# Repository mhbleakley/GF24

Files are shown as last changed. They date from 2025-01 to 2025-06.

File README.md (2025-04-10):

# GeoFence 2024



A dog collar with GNSS capabilities and an alarm, allowing the user to set a virtual fenced area. When the collar leaves the fenced area, the alarm sounds.

View schematic/board [here](https://kicanvas.org/?github=https%3A%2F%2Fgithub.com%2Fmhbleakley%2FGF24) (you will have to select board or schematic from right panel).

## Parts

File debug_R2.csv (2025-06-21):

Reference | Footprint | Manufacturer PN | Distributor Link
BT1 | MB-SW:Solder_Joint_1_2
BZ1 | MB-Buzzer:SMTB-0927-TW-R | 668-SMTB-0927-TW-RTR-ND | https://www.digikey.com/en/products/detail/pui-audio-inc/smtb-0927-tw-r/13165907
C1,C2,C6,C14,C17,C18 | Capacitor_SMD:C_0603_1608Metric | 399-13217-2-ND | https://www.digikey.com/en/products/detail/kemet/C1210C105K8RACTU/2216484
C3 | Capacitor_SMD:C_0603_1608Metric | 399-C0603C103K8RACTUTR-ND | https://www.digikey.com/en/products/detail/kemet/C0603C103K8RACTU/2199758
C4 | Capacitor_SMD:C_0805_2012Metric | 399-C1210C475K8RACTUTR-ND | https://www.digikey.com/en/products/detail/kemet/C1210C475K8RACTU/2216925
C5,C8,C10,C12,C13,C15,C16,C19 | Capacitor_SMD:C_0805_2012Metric | 399-C0805C104K8RACTUTR-ND | https://www.digikey.com/en/products/detail/kemet/C0805C104K8RACTU/2211745
C7,C9,C11 | Capacitor_SMD:C_0805_2012Metric | 399-C1210C106K8RACTUTR-ND | https://www.digikey.com/en/products/detail/kemet/C1210C106K8RACTU/2216503
D1,D2,D3,D4 | MB-Opto:WE-0603-Mono-Chip-Advance | 732-150060RS75003TR-ND | https://www.digikey.com/en/products/detail/w%C3%BCrth-elektronik/150060RS75003/16022171
D5,D6,D7,D8 | MB-Opto:WE-1204-Mono-Side | 732-5024-2-ND | https://www.digikey.com/en/products/detail/w%C3%BCrth-elektronik/155124GS73200/4490038
D9 | MB-SOD:SOD-123-2 | MMSD4148T1GOSTR-ND | https://www.digikey.com/en/products/detail/onsemi/mmsd4148t1g/919705
J1 | MB-Conn:GCT_USB4110GFA | 2073-USB4110-GF-A-2-ND | https://www.digikey.com/en/products/detail/gct/usb4110-gf-a/10384547
J4 | Connector_PinHeader_2.54mm:PinHeader_1x04_P2.54mm_Horizontal | S9016E-04-ND | https://www.digikey.com/en/products/detail/sullins-connector-solutions/GRPB041VWCN-RC/1786467
Q1 | Package_TO_SOT_SMD:SOT-323_SC-70 | MMBT3904LT1GOSTR-ND | https://www.digikey.com/en/products/detail/onsemi/mmbt3904lt1g/919601
R1 | MB-Generic:R0603_medium | 311-4.12KHRTR-ND | https://www.digikey.com/en/products/detail/yageo/rc0603fr-074k12l/727204
R2,R3 | MB-Generic:R0603_medium | 311-261HRTR-ND | https://www.digikey.com/en/products/detail/yageo/RC0603FR-07261RL/727095
R4,R5,R6,R8,R9 | MB-Generic:R0603_medium | 311-1.00KHRTR-ND | https://www.digikey.com/en/products/detail/yageo/rc0603fr-071kl/726843
R7 | MB-Generic:R0603_medium | 311-1.50KHRTR-ND | https://www.digikey.com/en/products/detail/yageo/rc0603fr-071k5l/726864
R10,R11,R12 | MB-Generic:R0603_medium | 311-10.0KHRTR-ND | https://www.digikey.com/en/products/detail/yageo/rc0603fr-0710kl/726880
R13 | MB-Generic:R0603_medium | 311-180HRTR-ND | https://www.digikey.com/en/products/detail/yageo/rc0603fr-07180rl/726994
R14,R15,R16 | MB-Generic:R0603_medium | 13-RC0603JR-072RLTR-ND | https://www.digikey.com/en/products/detail/yageo/RC0603JR-072RL/5918445
SW1,SW4 | MB-SW:Solder_Joint_1_2
SW2 | MB-SW:PTS815SJM250SMTRLFS | CKN12215-2-ND | https://www.digikey.com/en/products/detail/c-k/pts815sjm250smtrlfs/9947846
SW3 | Button_Switch_SMD:Nidec_Copal_CAS-120A | 563-1021-2-ND | https://www.digikey.com/en/products/detail/nidec-components-corporation/cjs-1200ta/948332
SW5 | MB-SW:Solder_Joint_1_2
TH1 | MB-Generic:R0603_medium | 490-18139-2-ND | https://www.digikey.com/en/products/detail/murata-electronics/ncu18xh103f6srb/7243451
TP1,TP2,TP3,TP4,TP5,TP6 | TestPoint:TestPoint_Pad_D1.5mm
U1 | Package_TO_SOT_SMD:SOT-223-6 | 296-13810-2-ND | https://www.digikey.com/en/products/detail/texas-instruments/tps79533dcqr/510347
U2 | MB-MSOP:10-MSOP-TE | LTC1733EMSE#TRPBFTR-ND | https://www.digikey.com/en/products/detail/analog-devices-inc/ltc1733emse-trpbf/961156
U3 | MB-GNSS:SAM-M10Q | 672-SAM-M10Q-00BTR-ND | https://www.digikey.com/en/products/detail/u-blox/sam-m10q-00b/16672678
U4 | Package_QFP:LQFP-48_7x7mm_P0.5mm | 497-8307-ND | https://www.digikey.com/en/products/detail/stmicroelectronics/STM32F102C8T6/1956086
X1 | Oscillator:Oscillator_SMD_ECS_2520MV-xxx-xx-4Pin_2.5x2.0mm | XC3030TR-ND | https://www.digikey.com/en/products/detail/ecs-inc/ecs-2520mv-160-cn-tr/9742387

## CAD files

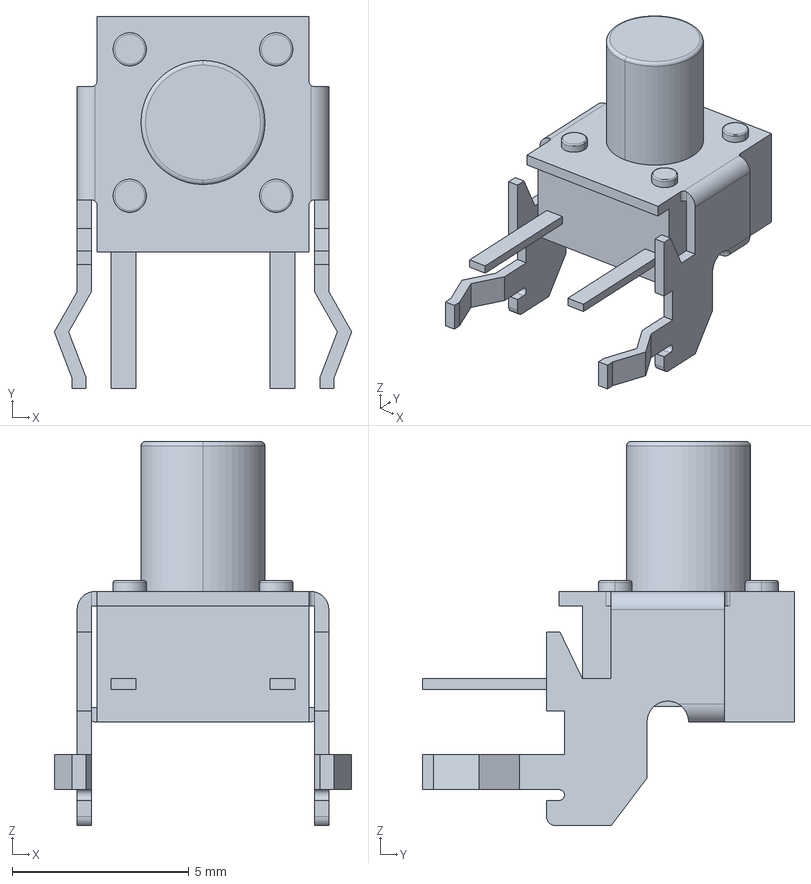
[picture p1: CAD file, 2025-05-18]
3D/1_1825027_7/c-1-1825027-7-g-3d.stp
8.41 x 10.5 x 10.9 mm

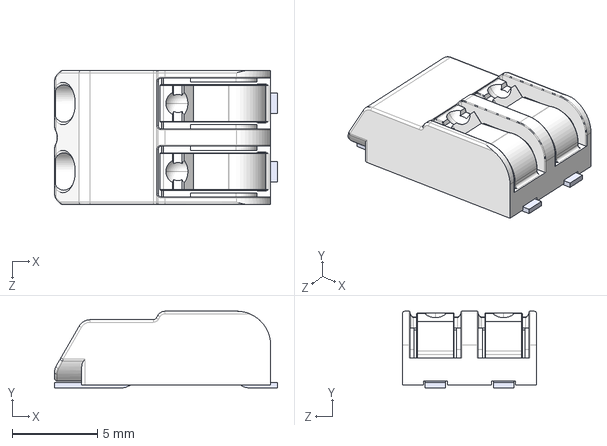
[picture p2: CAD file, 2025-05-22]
3D/2060_452_998_404/2060-452_998-404.step
13.1 x 4.50 x 7.90 mm

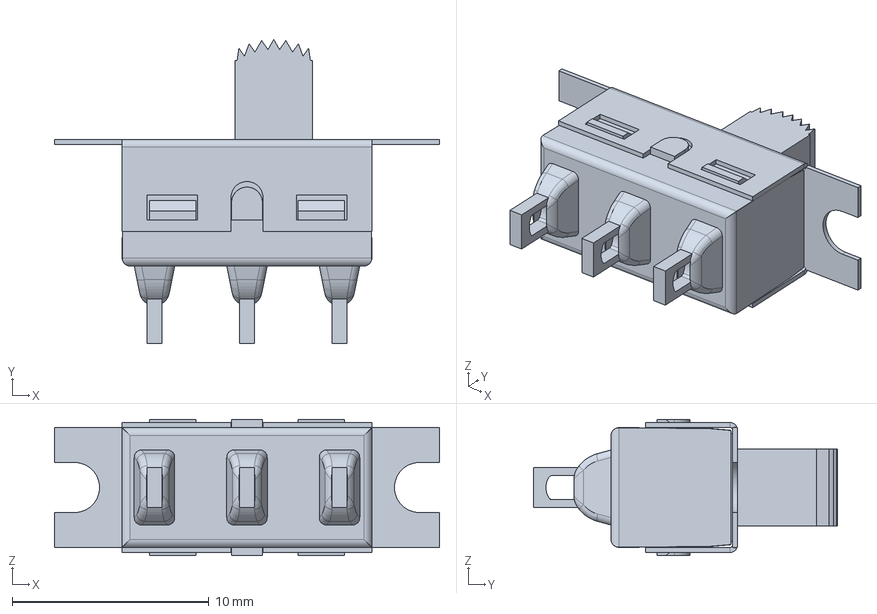
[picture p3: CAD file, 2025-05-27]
3D/CKCOMPONENTS_1101M1S3ZBE2/1101M1S3ZBE2.stp
19.6 x 15.4 x 6.91 mm

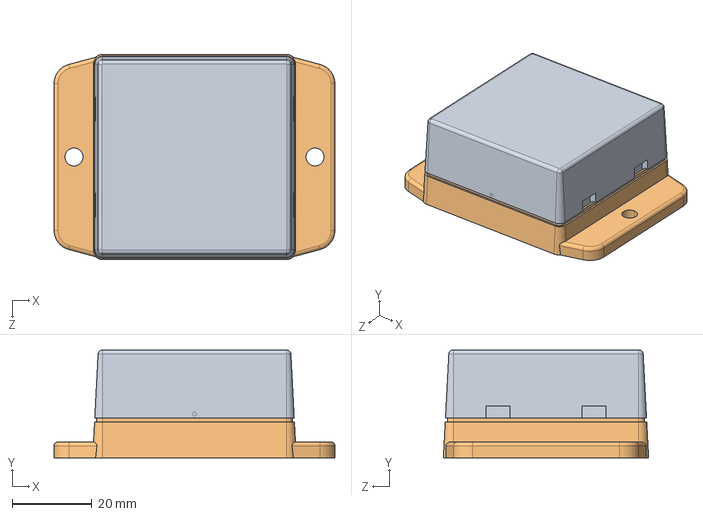
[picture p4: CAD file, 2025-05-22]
3D/CU-18422.Step
70.4 x 27.0 x 51.4 mm
18422-C
18422-B

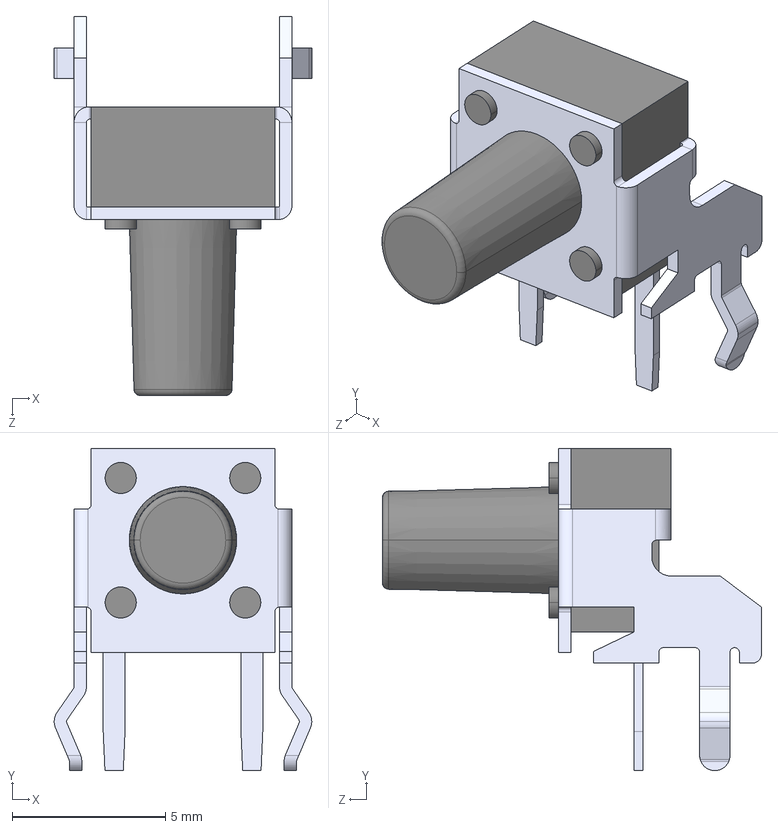
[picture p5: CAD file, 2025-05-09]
3D/1-1825027-1.step
8.41 x 10.5 x 12.4 mm

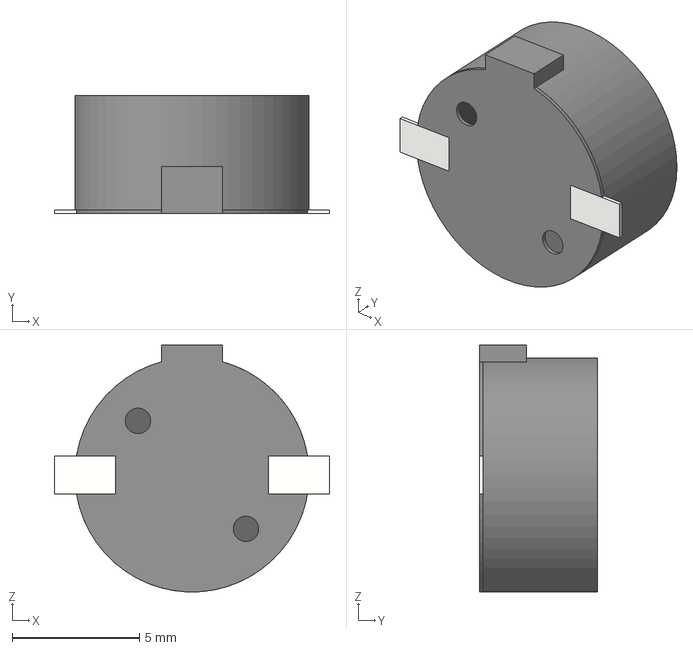
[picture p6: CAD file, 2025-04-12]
3D/SMTB-0927-TW-R--3DModel-STEP-461651.STEP
10.8 x 4.65 x 9.70 mm

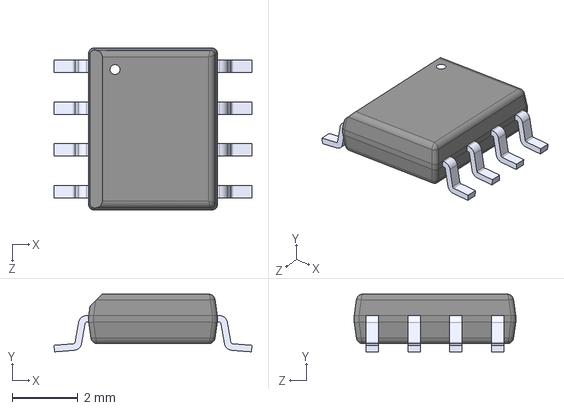
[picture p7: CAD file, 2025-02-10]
3D/M24C02-WMN6TP.step
6.00 x 1.75 x 4.90 mm

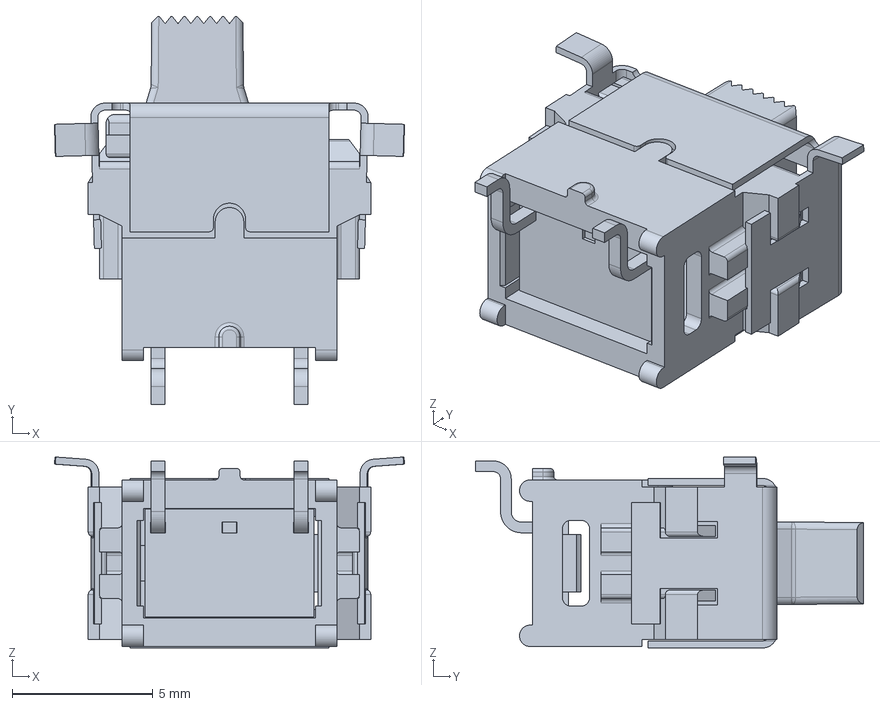
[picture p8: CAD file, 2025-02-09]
3D/ES02MSABE.stp
12.4 x 13.8 x 6.78 mm
ES02MSABE_PART1
ES02MSABE_PART2
ES02MSABE_PART3

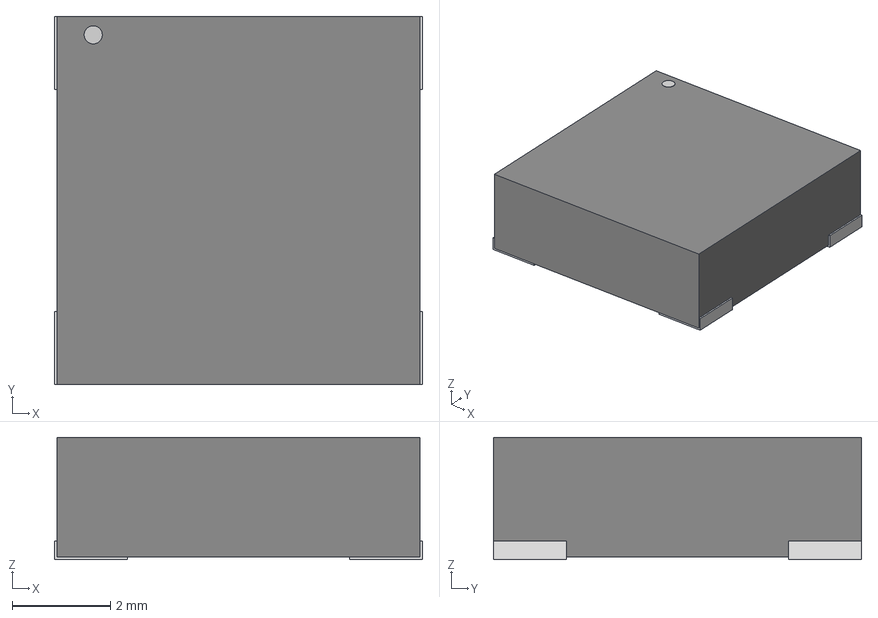
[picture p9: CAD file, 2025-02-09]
3D/ST-025BH_SOB.step
7.49 x 7.49 x 2.49 mm

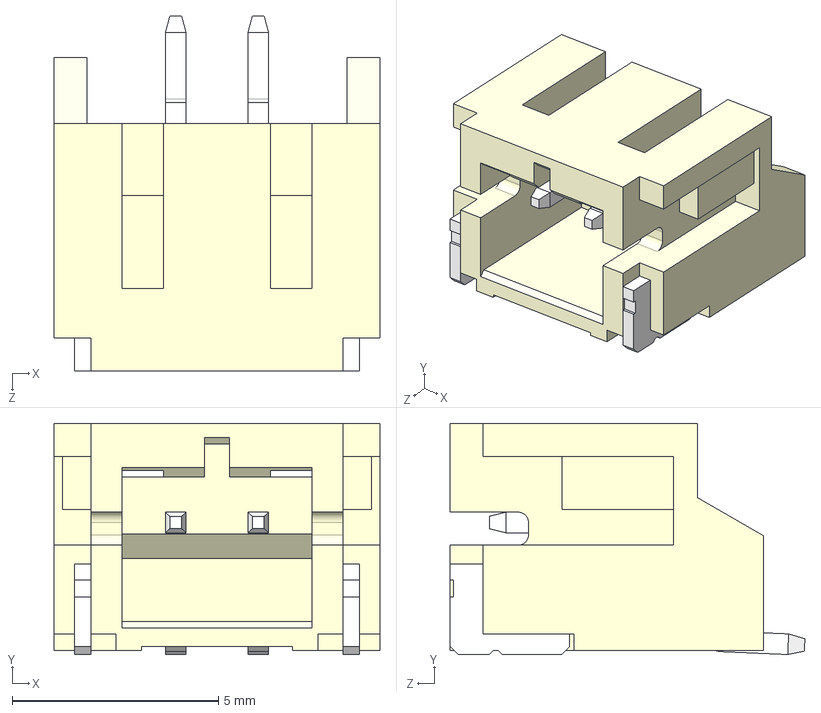
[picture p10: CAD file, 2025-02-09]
3D/S2B-PH-SM4-TB--3DModel-STEP-269445.STEP
7.90 x 5.60 x 8.60 mm

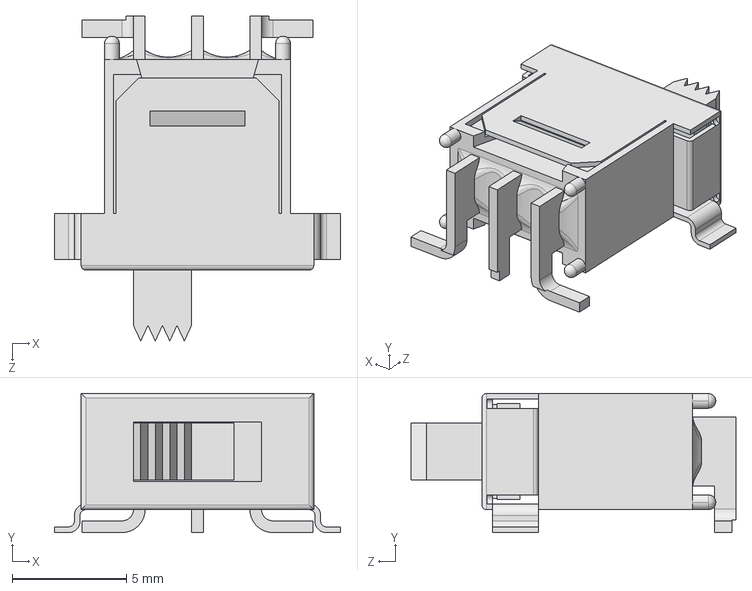
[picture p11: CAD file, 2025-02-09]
3D/500ASSP1SM6QE.step
12.5 x 6.08 x 14.2 mm

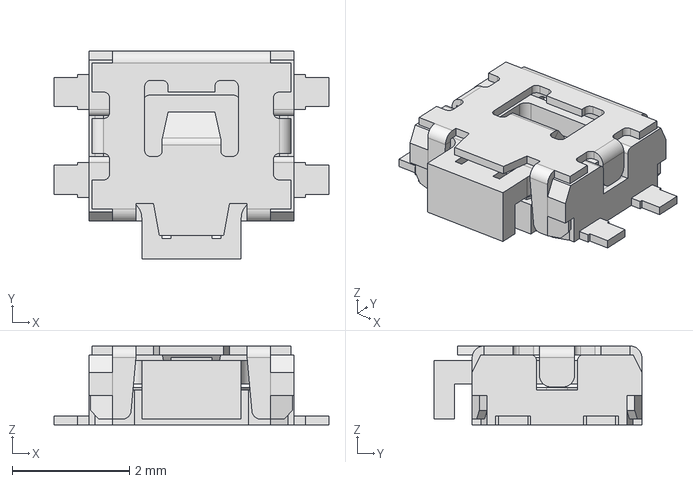
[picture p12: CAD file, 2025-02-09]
3D/TL1016AAFxxxQG.stp
4.70 x 3.55 x 1.35 mm

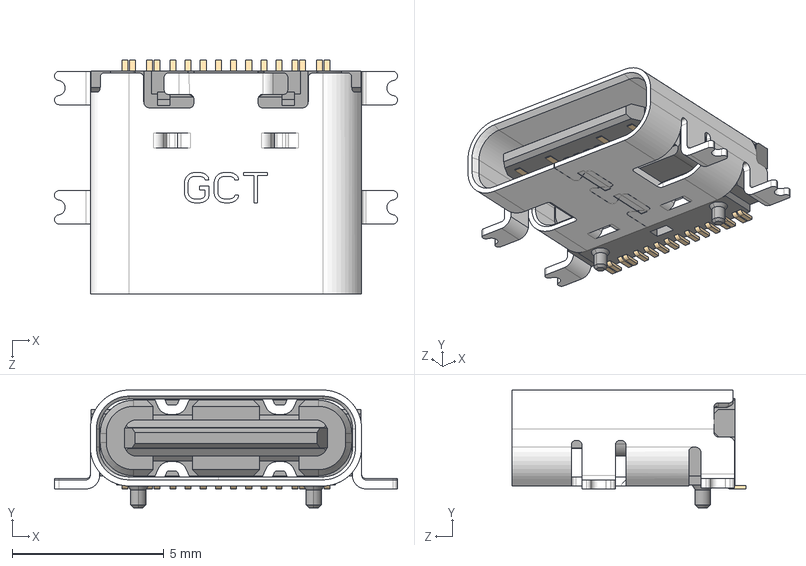
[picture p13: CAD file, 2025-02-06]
3D/USB4110GFA.step
11.3 x 3.89 x 7.70 mm

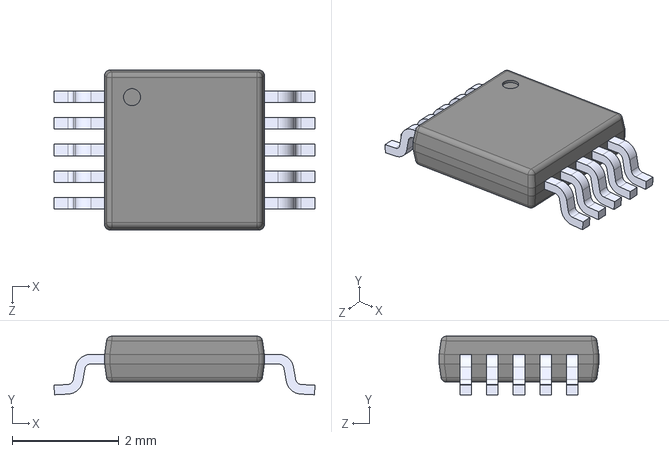
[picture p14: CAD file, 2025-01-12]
3D/LTC1733EMSE_TRPBF.step
4.90 x 1.10 x 3.00 mm

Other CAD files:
3D/NX2016SA_NDK.step
3D/1101M2S5AQE2.stp
3D/3220-10-0100-00--3DModel-STEP-56544.STEP
3D/PTS815SJM250SMTRLFS.stp
3D/0533980671--3DModel-STEP-361473.STEP
3D/0533980671/0533980671.step
3D/2137160001.step
3D/54.STEP
3D/APBDA3020.STEP
3D/APDA3020.STEP
3D/C0402C103K9RACTU.STEP
3D/C0603C103K9RACTU.STEP
3D/C0805C104K9RACTU.step
3D/C1206C475K9RACTU.step
3D/CJS-1200TA.step
3D/CSQG703BP.step
3D/ETQ-P3M2R2HFP.STEP
3D/LM3671MF-3.3.step
3D/M24256-BFMC6TG.step
3D/MAX-M10S-00B--3DModel-STEP-269445.STEP
3D/MMSD4148T1G.STEP
3D/RC0603FR-0710KL.STEP
3D/RC1206JR-1010KL.step
3D/SAM-M8Q-0.STEP
3D/TPS74533PQWDRVRQ1.step

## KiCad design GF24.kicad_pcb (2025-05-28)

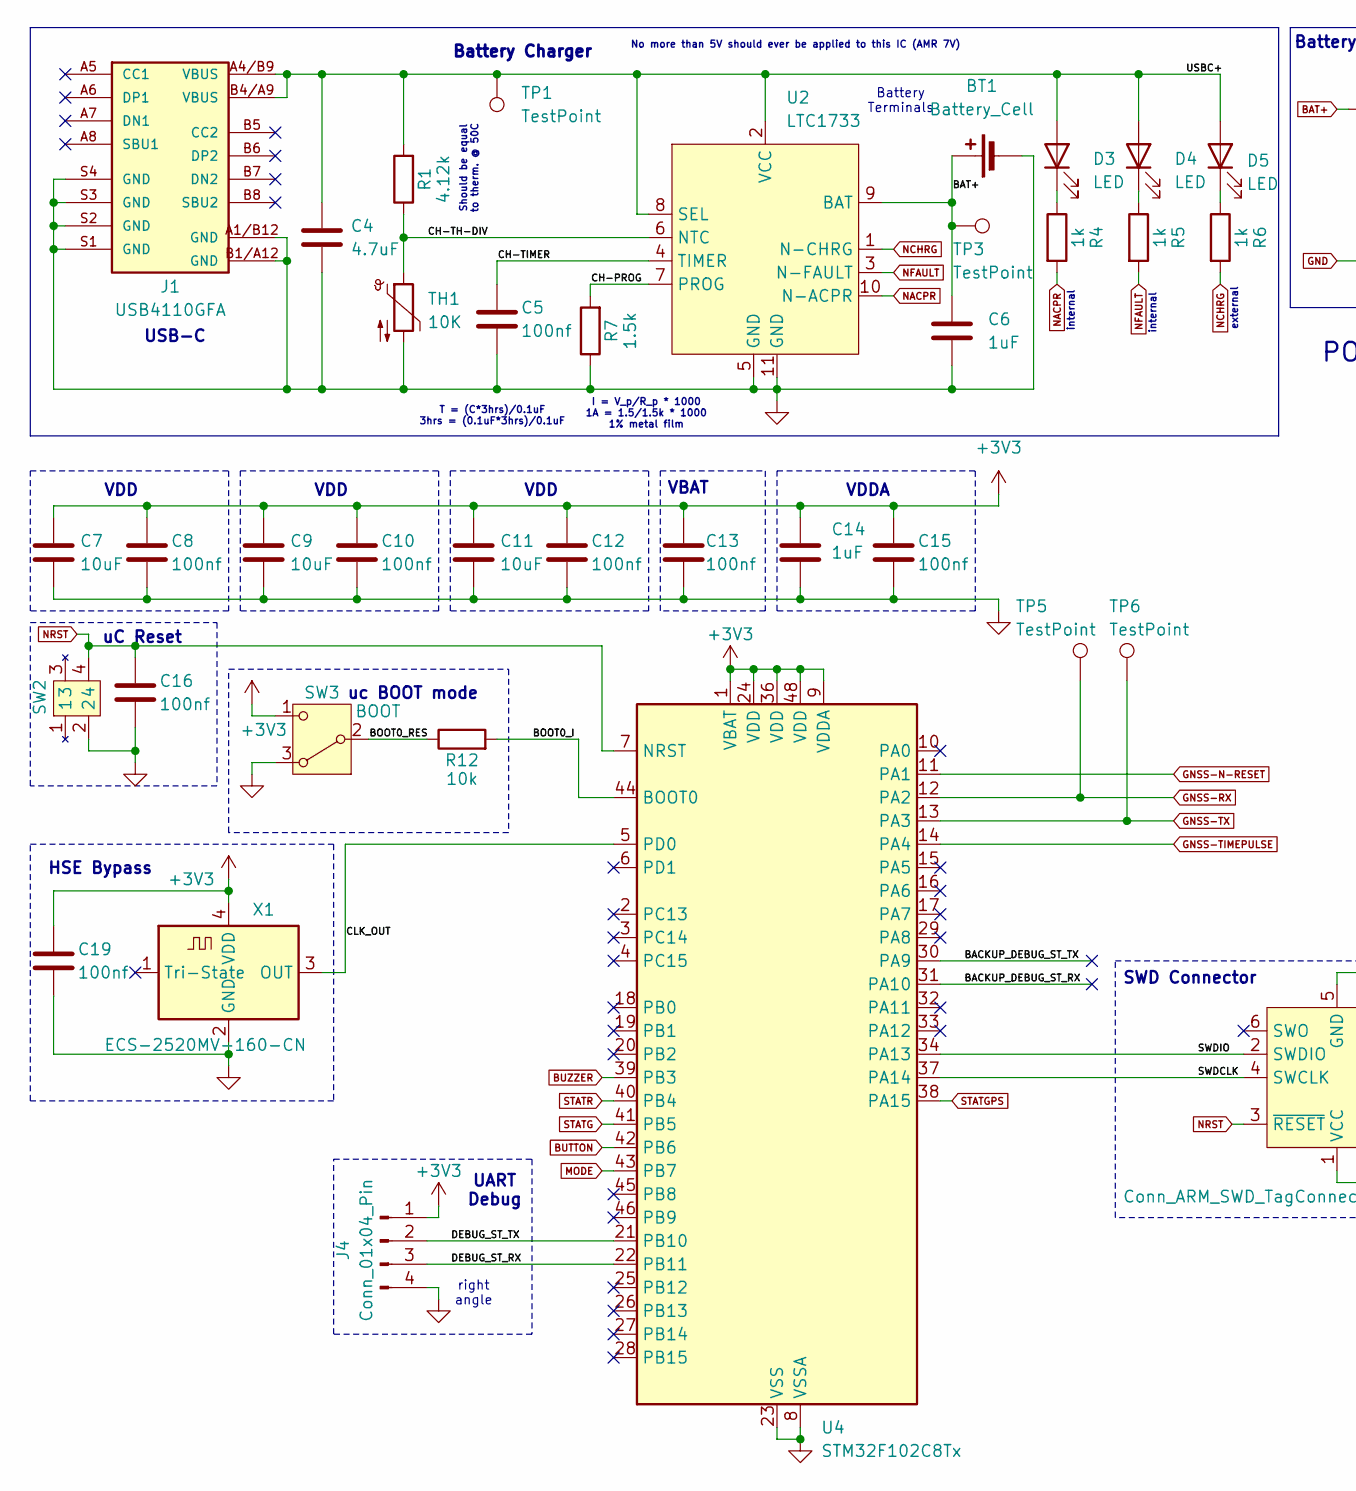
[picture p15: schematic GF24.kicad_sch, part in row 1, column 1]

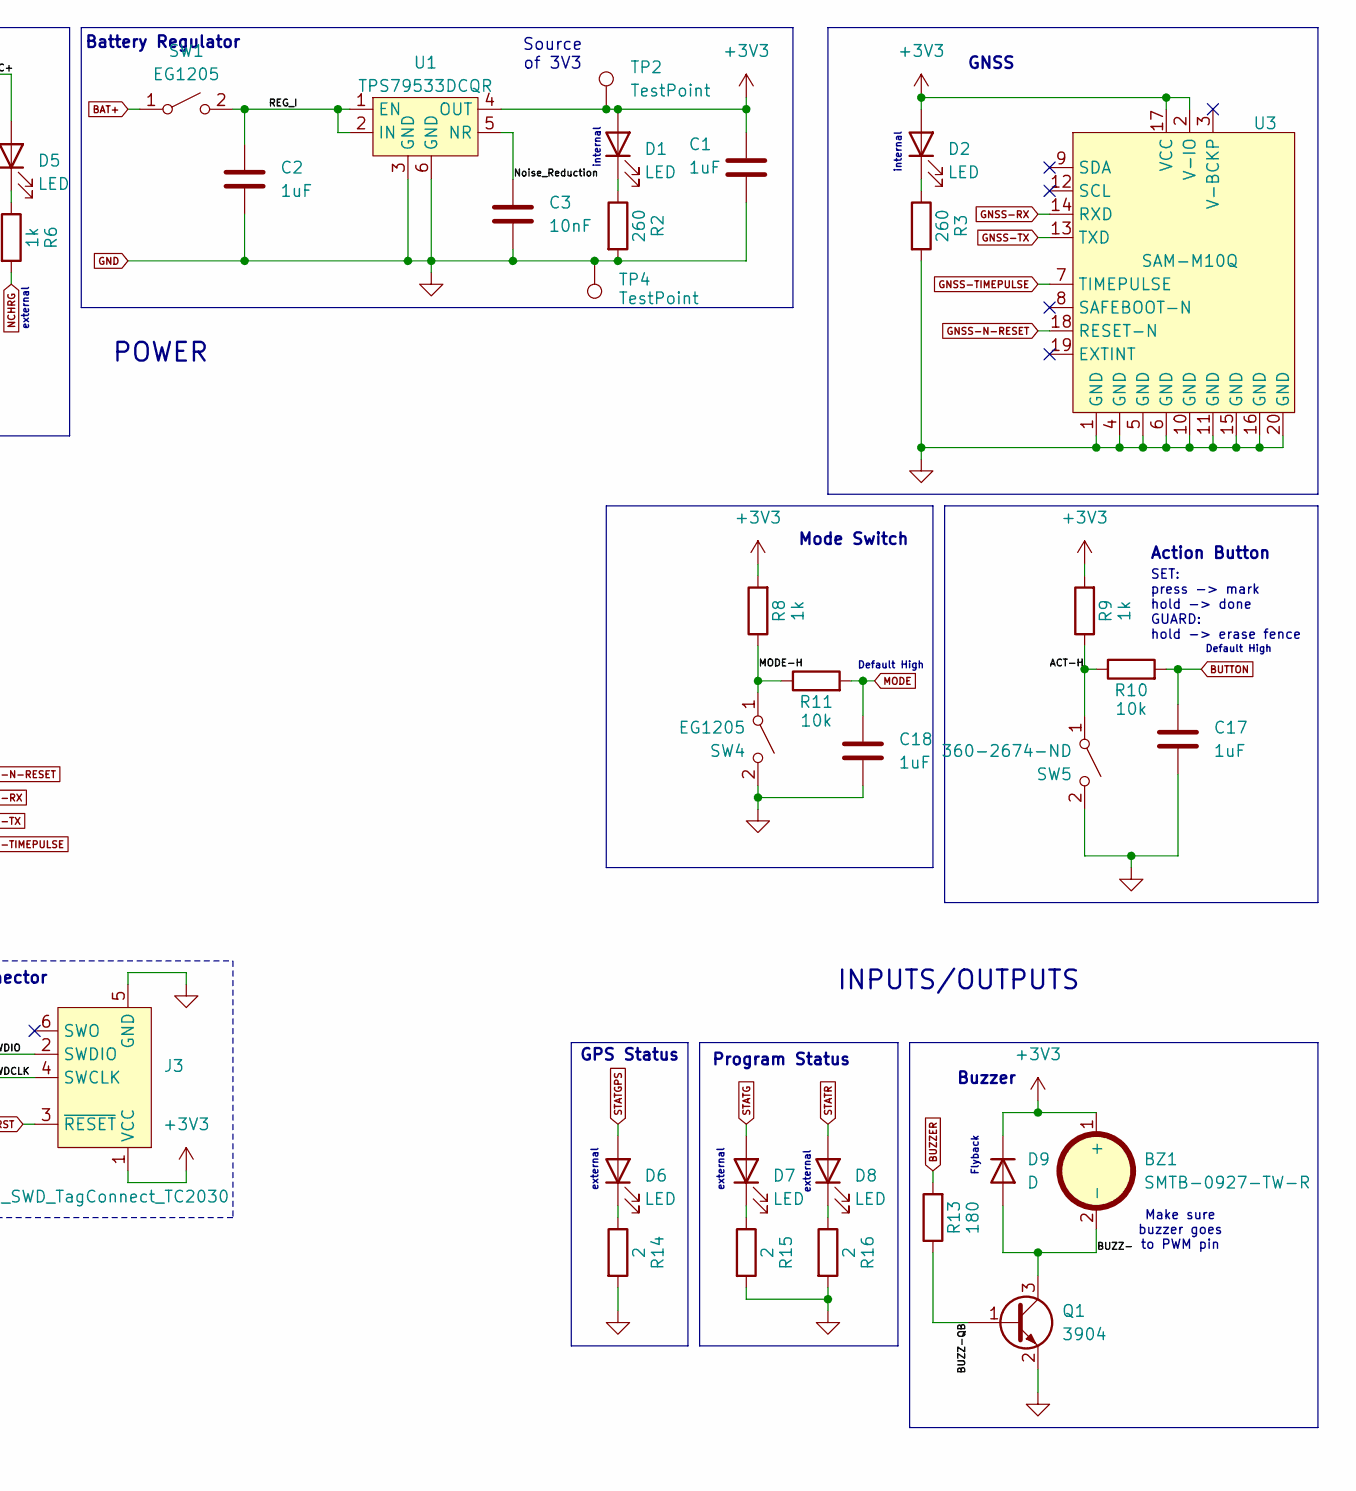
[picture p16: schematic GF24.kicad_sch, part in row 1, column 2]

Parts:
BT1: Battery_Cell; Solder_Joint_1_2
BZ1: SMTB-0927-TW-R; Manufacturer PN 668-SMTB-0927-TW-RTR-ND
C1, C2, C6, C14, C17, C18: 1uF; C_0603_1608Metric; Manufacturer PN 399-13217-2-ND
C3: 10nF; C_0603_1608Metric; Manufacturer PN 399-C0603C103K8RACTUTR-ND
C4: 4.7uF; C_0805_2012Metric; Manufacturer PN 399-C1210C475K8RACTUTR-ND
C5, C8, C10, C12, C13, C15, C16, C19: 100nf; C_0805_2012Metric; Manufacturer PN 399-C0805C104K8RACTUTR-ND
C7, C9, C11: 10uF; C_0805_2012Metric; Manufacturer PN 399-C1210C106K8RACTUTR-ND
D1, D2, D3, D4: LED; WE-0603-Mono-Chip-Advance; Manufacturer PN 732-150060RS75003TR-ND
D5, D6, D7, D8: LED; WE-1204-Mono-Side; Manufacturer PN 732-5024-2-ND
D9: D; SOD-123-2; Manufacturer PN MMSD4148T1GOSTR-ND
J1: USB4110GFA; GCT_USB4110GFA; Manufacturer PN 2073-USB4110-GF-A-2-ND; DigiKey_Part_Number 2073-USB4110-GF-A-2-ND
J3: Conn_ARM_SWD_TagConnect_TC2030; Tag-Connect_TC2030-IDC-FP_2x03_P1.27mm_Vertical
J4: Conn_01x04_Pin; PinHeader_1x04_P2.54mm_Horizontal; Manufacturer PN S9016E-04-ND
Q1: 3904; SOT-323_SC-70; Manufacturer PN MMBT3904LT1GOSTR-ND
R1: 4.12k; R0603_medium; Manufacturer PN 311-4.12KHRTR-ND
R2, R3: 260; R0603_medium; Manufacturer PN 311-261HRTR-ND
R4, R5, R6, R8, R9: 1k; R0603_medium; Manufacturer PN 311-1.00KHRTR-ND
R7: 1.5k; R0603_medium; Manufacturer PN 311-1.50KHRTR-ND
R10, R11, R12: 10k; R0603_medium; Manufacturer PN 311-10.0KHRTR-ND
R13: 180; R0603_medium; Manufacturer PN 311-180HRTR-ND
R14, R15, R16: 2; R0603_medium; Manufacturer PN 13-RC0603JR-072RLTR-ND
SW1, SW4: EG1205; Solder_Joint_1_2
SW2: PTS815SJM250SMTRLFS; Manufacturer PN CKN12215-2-ND
SW3: BOOT; Nidec_Copal_CAS-120A; Manufacturer PN 563-1021-2-ND
SW5: 360-2674-ND; Solder_Joint_1_2
TH1: 10K; R0603_medium; Manufacturer PN 490-18139-2-ND
TP1, TP2, TP3, TP4, TP5, TP6: TestPoint; TestPoint_Pad_D1.5mm
U1: TPS79533DCQR; SOT-223-6; Manufacturer PN 296-13810-2-ND
U2: LTC1733; 10-MSOP-TE; Manufacturer PN LTC1733EMSE#TRPBFTR-ND
U3: SAM-M10Q; Manufacturer PN 672-SAM-M10Q-00BTR-ND
U4: STM32F102C8Tx; LQFP-48_7x7mm_P0.5mm; Manufacturer PN 497-8307-ND
X1: ECS-2520MV-160-CN; Oscillator_SMD_ECS_2520MV-xxx-xx-4Pin_2.5x2.0mm; Manufacturer PN XC3030TR-ND

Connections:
+3V3: BZ1.1 (+), C1.1, C7.1, C8.1, C9.1, C10.1, C11.1, C12.1, C13.1, C14.1, C15.1, C19.1, D1.2 (A), D2.2 (A), D9.1 (K), J3.1 (VCC), J4.1, R8.2, R9.2, SW3.1 (C), TP2.1, U1.4 (OUT), U3.2 (V-IO), U3.17 (VCC), U4.1 (VBAT), U4.9 (VDDA), U4.24 (VDD), U4.36 (VDD), U4.48 (VDD), X1.4 (VDD)
/ACT-H: R9.1, R10.1, SW5.1 (A)
/BACKUP_DEBUG_ST_RX: U4.31 (PA10)
/BACKUP_DEBUG_ST_TX: U4.30 (PA9)
/BOOT0_I: R12.2, U4.44 (BOOT0)
/BOOT0_RES: R12.1, SW3.2 (B)
/BUZZ-: BZ1.2 (-), D9.2 (A), Q1.3 (C)
/BUZZ-QB: Q1.1 (B), R13.1
/CH-PROG: R7.2, U2.7 (PROG)
/CH-TH-DIV: R1.1, TH1.1, U2.6 (NTC)
/CH-TIMER: C5.1, U2.4 (TIMER)
/CLK_OUT: U4.5 (PD0), X1.3 (OUT)
/DEBUG_ST_RX: J4.3, U4.22 (PB11)
/DEBUG_ST_TX: J4.2, U4.21 (PB10)
/MODE-H: R8.1, R11.1, SW4.1 (A)
/Noise_Reduction: C3.1, U1.5 (NR)
/REG_I: C2.1, SW1.2 (B), U1.1 (EN), U1.2 (IN)
/SWDCLK: J3.4 (SWCLK), U4.37 (PA14)
/SWDIO: J3.2 (SWDIO), U4.34 (PA13)
/USBC+: C4.1, D3.2 (A), D4.2 (A), D5.2 (A), J1.A4/B9 (VBUS), J1.B4/A9 (VBUS), R1.2, TP1.1, U2.2 (VCC), U2.8 (SEL)
BAT+: BT1.1 (+), C6.1, SW1.1 (A), TP3.1, U2.9 (BAT)
BUTTON: C17.1, R10.2, U4.42 (PB6)
BUZZER: R13.2, U4.39 (PB3)
GND: BT1.2 (-), C1.2, C2.2, C3.2, C4.2, C5.2, C6.2, C7.2, C8.2, C9.2, C10.2, C11.2, C12.2, C13.2, C14.2, C15.2, C16.2, C17.2, C18.2, C19.2, J1.A1/B12 (GND), J1.B1/A12 (GND), J1.S1 (GND), J1.S2 (GND), J1.S3 (GND), J1.S4 (GND), J3.5 (GND), J4.4, Q1.2 (E), R2.2, R3.2, R7.1, R14.2, R15.2, R16.2, SW2.2, SW3.3 (A), SW4.2 (B), SW5.2 (B), TH1.2, TP4.1, U1.3 (GND), U1.6 (GND), U2.5 (GND), U2.11 (GND), U3.1 (GND), U3.4 (GND), U3.5 (GND), U3.6 (GND), U3.10 (GND), U3.11 (GND), U3.15 (GND), U3.16 (GND), U3.20 (GND), U4.8 (VSSA), U4.23 (VSS), U4.35 (VSS), U4.47 (VSS), X1.2 (GND)
GNSS-N-RESET: U3.18 (RESET-N), U4.11 (PA1)
GNSS-RX: TP5.1, U3.14 (RXD), U4.12 (PA2)
GNSS-TIMEPULSE: U3.7 (TIMEPULSE), U4.14 (PA4)
GNSS-TX: TP6.1, U3.13 (TXD), U4.13 (PA3)
MODE: C18.1, R11.2, U4.43 (PB7)
NACPR: R4.2, U2.10 (N-ACPR)
NCHRG: R6.2, U2.1 (N-CHRG)
NFAULT: R5.2, U2.3 (N-FAULT)
NRST: C16.1, J3.3 (~RESET), SW2.4, U4.7 (NRST)
unnamed: D1.1 (K), R2.1
unnamed: D2.1 (K), R3.1
unnamed: D3.1 (K), R4.1
unnamed: D4.1 (K), R5.1
unnamed: D5.1 (K), R6.1
unnamed: D6.1 (K), R14.1
unnamed: D7.1 (K), R15.1
unnamed: D8.1 (K), R16.1
STATG: D7.2 (A), U4.41 (PB5)
STATGPS: D6.2 (A), U4.38 (PA15)
STATR: D8.2 (A), U4.40 (PB4)

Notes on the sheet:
Default High
SET: press -> mark hold -> done GUARD: hold -> erase fence
VDD
Should be equal to therm. @ 50C
external
Battery Terminals
INPUTS/OUTPUTS
internal
VDDA
USB-C
Buzzer
POWER
GNSS
right angle
uc BOOT mode
Mode Switch
Flyback
T = (C*3hrs)/0.1uF 3hrs = (0.1uF*3hrs)/0.1uF
UART Debug
uC Reset
Program Status
SWD Connector
GPS Status
No more than 5V should ever be applied to this IC (AMR 7V)
Source of 3V3
VBAT
Make sure buzzer goes to PWM pin
Battery Regulator
HSE Bypass
I = V_p/R_p * 1000 1A = 1.5/1.5k * 1000 1% metal film
Battery Charger
Action Button

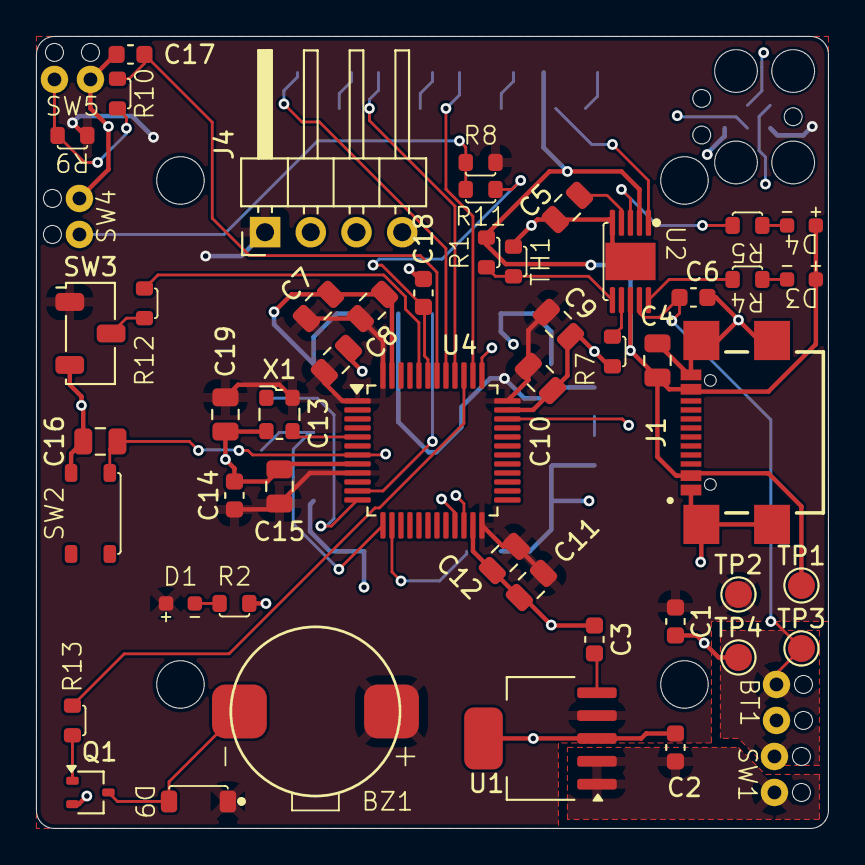
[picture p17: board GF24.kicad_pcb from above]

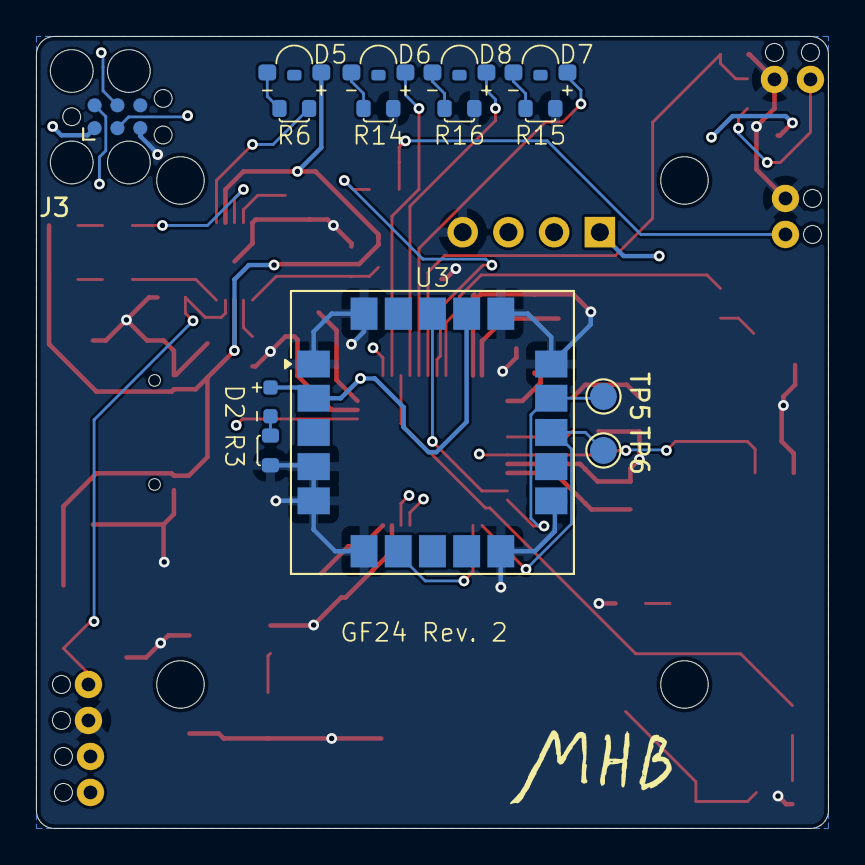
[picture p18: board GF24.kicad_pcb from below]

Board: 4 copper layers, 44.0 x 44.0 mm, 67 parts (14 on the bottom side), 42 nets.

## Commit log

2024-12-15 updated power
    [GF24.kicad_sch]
2024-12-15 switching devices
2024-12-16 changed NRST
    [GF24.kicad_sch]
2024-12-17 sorted BOOT0 for now, added HSE
    [GF24.kicad_sch]
2024-12-20 added MAX-M10S symbol/footprint
    [GF24.kicad_sch]
2024-12-22 didn't update
    [GF24.kicad_sch]
2024-12-24 added cap footprints
    [GF24.kicad_sch]
2024-12-26 added boot mode and battery
    [GF24.kicad_sch]
2024-12-26 added voltage regulator
    [GF24.kicad_sch]
2024-12-27 added all footprints, not all final
    [54.STEP, C0603C103K9RACTU.STEP, C0805C104K9RACTU.step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]
2024-12-29 someday I'll write useful commit messages
    [GF24.kicad_sch]
2024-12-30 button circuit complete
    [GF24.kicad_sch]
2024-12-31 added initial battery charge circuit
    [GF24.kicad_sch]
2024-12-31 added passives
    [GF24.kicad_sch]
2025-01-02 beats me
    [GF24.kicad_sch]
2025-01-03 selected components for battery charger
    [GF24.kicad_sch]
2025-01-06 updated battery regulator circuit. oof
    [GF24.kicad_sch]
2025-01-07 started to add EEPROM
    [GF24.kicad_sch]
2025-01-10 swapped GNSS again. Close to done with schematic
    [GF24.kicad_sch]
2025-01-10 added status LEDs
    [GF24.kicad_sch]
2025-01-11 fixed PG indicator, grouped parts functionally
    [2137160001.step, GF24.kicad_sch]
2025-01-11 changed most LED circuits which deal with open drain outputs
    [GF24.kicad_sch]
2025-01-12 fixed other LEDs, added or edited many footprints
    [2137160001.step, APBDA3020.STEP, APDA3020.STEP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]
2025-01-12 schematic done. most footprints done. now for the layout. oof
    [1101M2S5AQE2.stp, 3220-10-0100-00--3DModel-STEP-56544.STEP, CJS-1200TA.step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]
2025-01-21 some layout changes
    [GF24.kicad_pcb, GF24.kicad_sch]
2025-01-23 started traces. need to check footprints are correct i.e. regulator
    [GF24.kicad_pcb, GF24.kicad_sch]
2025-01-23 drew 3v plane
    [GF24.kicad_pcb]
2025-01-24 fixed broken footprint
    [GF24.kicad_pcb, GF24.kicad_sch]
2025-01-24 fixed some small ERC/DRC issues
    [GF24.kicad_pcb, GF24.kicad_sch]
2025-01-24 updated power planes
    [GF24.kicad_pcb, GF24.kicad_sch]
2025-01-25 possibly done with routing
    [GF24.kicad_pcb, GF24.kicad_sch]
2025-01-25 gerber and drill test
    [GF24-B_Cu.gbr, GF24-B_Mask.gbr, GF24-B_Paste.gbr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]
2025-02-06 going to try and reroute everything
    [GF24.kicad_pcb, GF24.kicad_sch, USB4110GFA.step]
2025-02-09 making things smaller
    [500ASSP1SM6QE.step, ES02MSABE.stp, GF24.kicad_pcb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]
2025-02-10 added mouse bites. need to do stackup
    [0533980671--3DModel-STEP-361473.STEP, 0533980671.step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]
2025-02-10 board setup mostly complete. need to do net classes properly
    [GF24.kicad_pcb]
2025-02-10 initial layout
    [GF24.kicad_pcb]
2025-02-11 another round of layout
    [GF24.kicad_pcb]
2025-02-11 still need to add test points, BOM
    [GF24.kicad_pcb]
2025-02-13 added some final touches
    [GF24.kicad_pcb, GF24.kicad_sch]
2025-02-15 no actual changes
    [GF24_parts.csv]
2025-03-10 added pos files
    [GF24-B_Cu.gbr, GF24-B_Mask.gbr, GF24-B_Paste.gbr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]
2025-04-12 swapped buzzer
    [GF24.kicad_sch, SMTB-0927-TW-R--3DModel-STEP-461651.STEP]
2025-04-14 changed LEDs for charging
    [GF24.kicad_sch]
2025-04-14 started wiring 555
    [GF24.kicad_sch]
2025-05-06 updating regulator
    [GF24.kicad_sch]
2025-05-09 soft complete Rev 2 schematic
    [1-1825027-1.step, GF24.kicad_sch]
2025-05-16 changed status LEDs based on testing
    [GF24.kicad_sch]
2025-05-18 need to finish placement but this is an almost completed R2
    [GF24.kicad_pcb, GF24.kicad_sch, c-1-1825027-7-g-3d.stp]
2025-05-22 going to make some changes to the I/O
    [CU-18422.Step, GF24.kicad_pcb, GF24.kicad_sch]
2025-05-22 added Wago
    [2060-452_998-404.step, GF24.kicad_pcb, GF24.kicad_sch]
2025-05-27 3D done, started routing
    [1101M1S3ZBE2.stp, GF24.kicad_pcb, GF24.kicad_sch]
2025-05-28 finished routing for Rev 2
    [GF24-B_Cu.gbr, GF24-B_Mask.gbr, GF24-B_Paste.gbr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]
2025-05-29 updated BOM, ordered board/components
    [GF24-B_Cu.gbr, GF24-B_Mask.gbr, GF24-B_Paste.gbr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]
2025-06-21 I ordered the wrong size capacitors
    [GF24.csv, GF24_parts.csv, debug_R2.csv]

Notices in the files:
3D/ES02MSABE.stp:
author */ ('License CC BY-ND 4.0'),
